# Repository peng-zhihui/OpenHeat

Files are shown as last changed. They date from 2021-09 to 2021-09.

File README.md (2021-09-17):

# OpenHeat：开源智能加热台

> 用于PCB回流焊的实用加热台，比较炫酷，可能目前市面上 **颜值最高** & **功能最强** 的加热台。

**参数：** 硬件方面基于`ESP32PICO-D4`芯片，输入电源`24V/10A`，最大功率200W，加热温度最高300℃；带蓝牙功能，***后续有空的话我会开发手机APP用于设置升温曲线*** 。

## 21-9-17 修复说明：

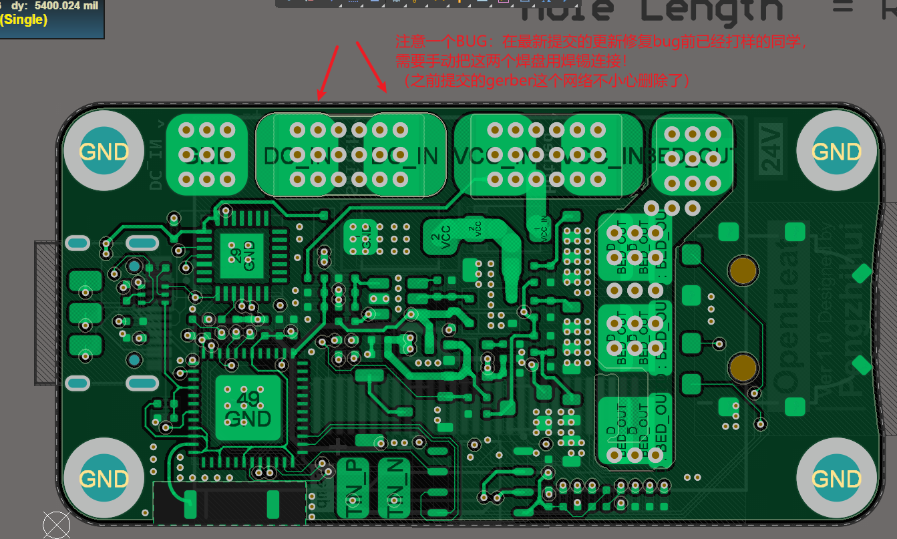
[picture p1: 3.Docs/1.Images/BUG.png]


---

## 关于本项目

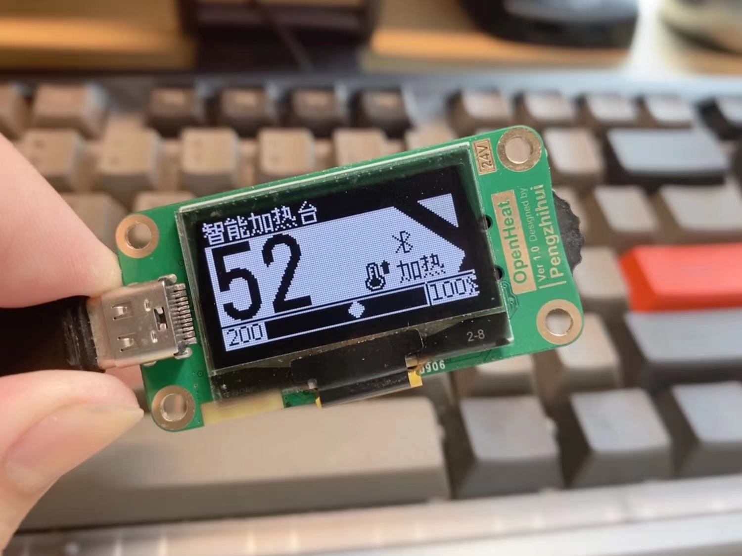
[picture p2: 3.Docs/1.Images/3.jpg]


* 本项目参考了 [createskyblue](https://gitee.com/createskyblue) / [OpenT12](https://gitee.com/createskyblue/OpenT12)开源T12电烙铁项目的固件，感谢这位同学设计的优秀交互动画体验，UI设计深得我心哈哈~

* 另外铝基板热床的设计采用了[MRobot-Origin](https://github.com/MRobot-Origin)/ [GS_Hbed](https://github.com/MRobot-Origin/GS_Hbed)同学的分型曲线设计，非常有创意~

## 使用说明

#### 1. 打样说明

直接用Hardware文件夹里的Gerber文件打样即可：主控制器为4层PCB，无特殊工艺要求；热床为铝基板PCB，可以在嘉立创打样。

> 铝基板是一种专门用来散热的PCB板材，大家看到的很多大功率LED灯珠就是这种，前阵子嘉立创开放了铝基板打样业务，还很便宜。所以相比于设计一个金属块做热床，这种方式不但成本低而且美观实用。

另外其实还有一块可选两层板作为固定件的，这个我还没来得及设计，也很简单，大家可以根据自己情况画一个，或者直接3D打印结构件固定也行。

#### 2. 固件说明

固件我这边是基于PlatformIO移植的，所以大家用这个平台的话直接打开下载就行了；如果是用Arduino IDE的话，先安装Library里面的库文件，然后一样下载。

固件库没有完全配置完成（因为原版固件是设计为电烙铁使用的），晚些我硬件都就位了会调试好固件供大家直接下载。

#### 3. 关于结构件

这个我也还在设计，我的风格肯定是以美观小巧为主，大家可以等我放出3D打印文件。

#### 4. 关于温度传感器

我这边是用的是K型热电偶，在PCB上已经集成了采集芯片，需要自己买一个表贴式的K型热电偶连接到板子下方的两个焊盘。

> 注意热电偶和热床的接触要绝缘，用高温胶带隔一下就行。另外热电偶是有极性的，如果发现加热后温度反而下降说明接反了。
>
> 现在代码中还没有加热电偶的代码，晚一点有空了会调好完整固件。大家自己添加也很容易，MAX6675使用SPI驱动，Arduino平台有很多例程。

#### 5. 关于元器件BOM

**注意！！！** C9电容一定要选耐压足够的，因为是并联到24V的VCC上，如果耐压不够短路的话可以看到烟花！！

#### 接线图

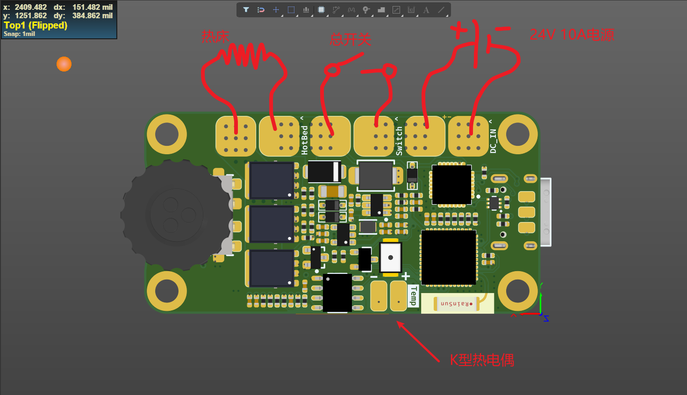
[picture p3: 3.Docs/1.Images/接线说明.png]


## 欢迎star支持 :D

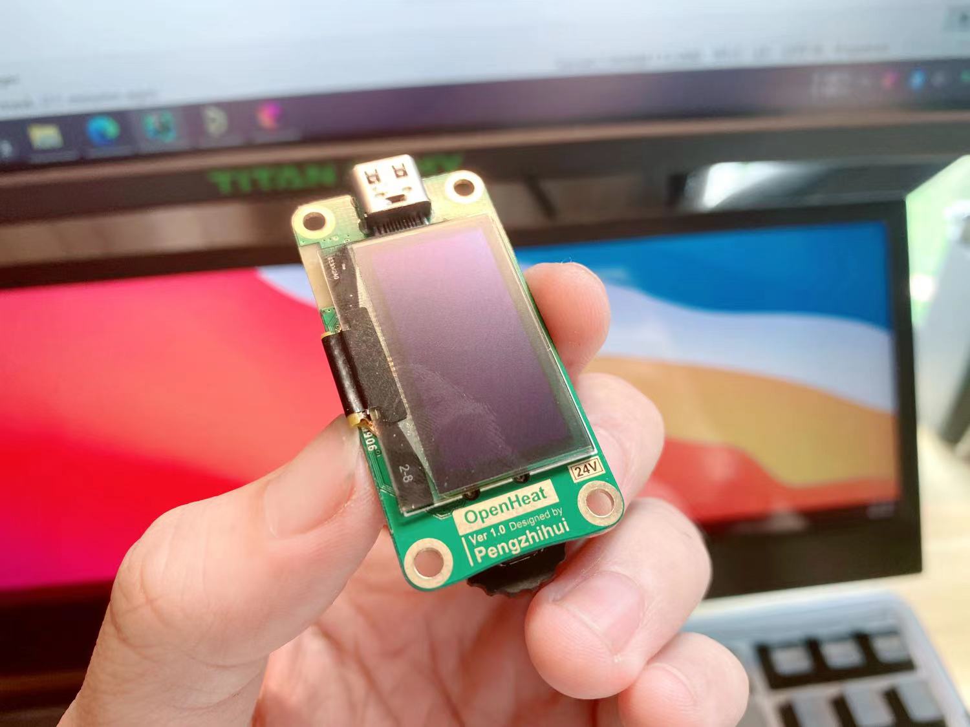
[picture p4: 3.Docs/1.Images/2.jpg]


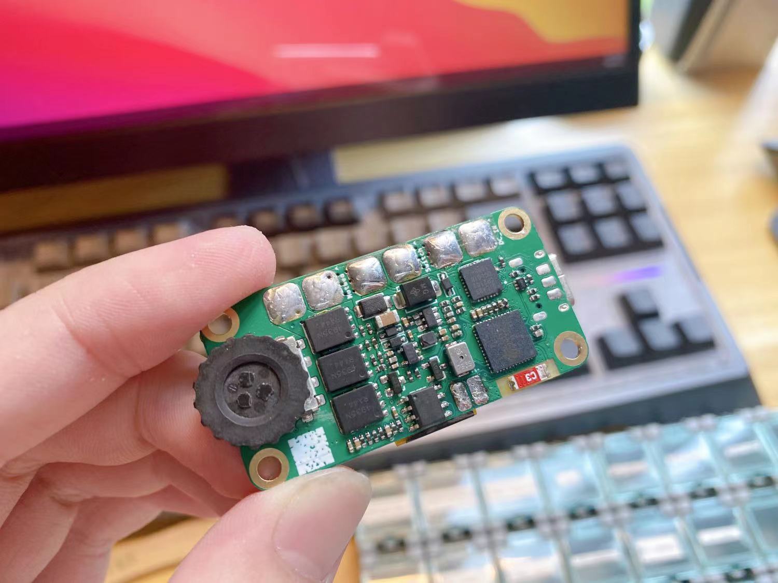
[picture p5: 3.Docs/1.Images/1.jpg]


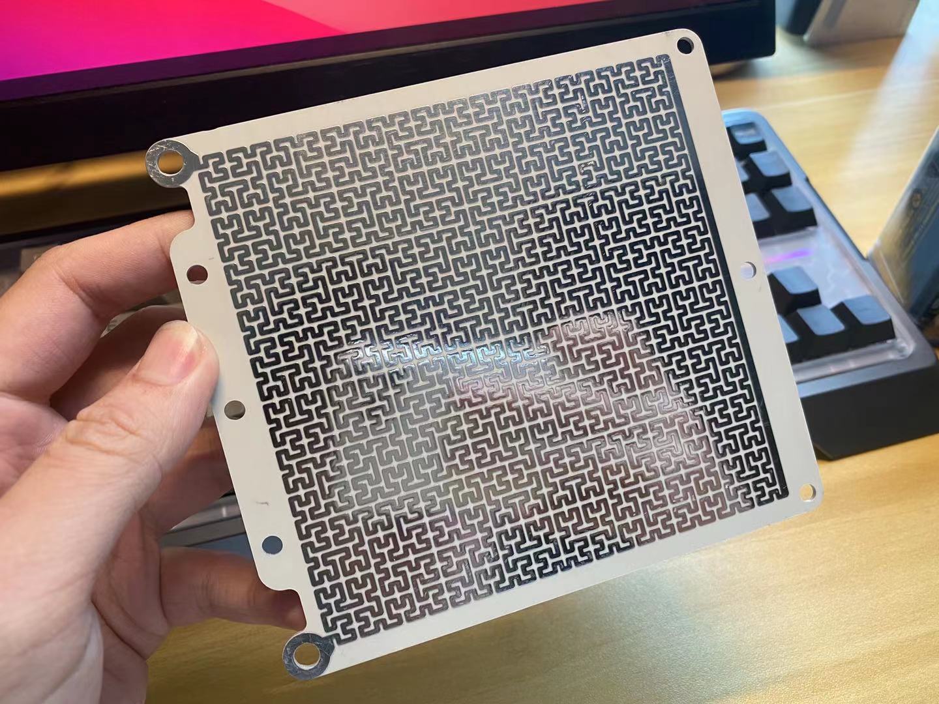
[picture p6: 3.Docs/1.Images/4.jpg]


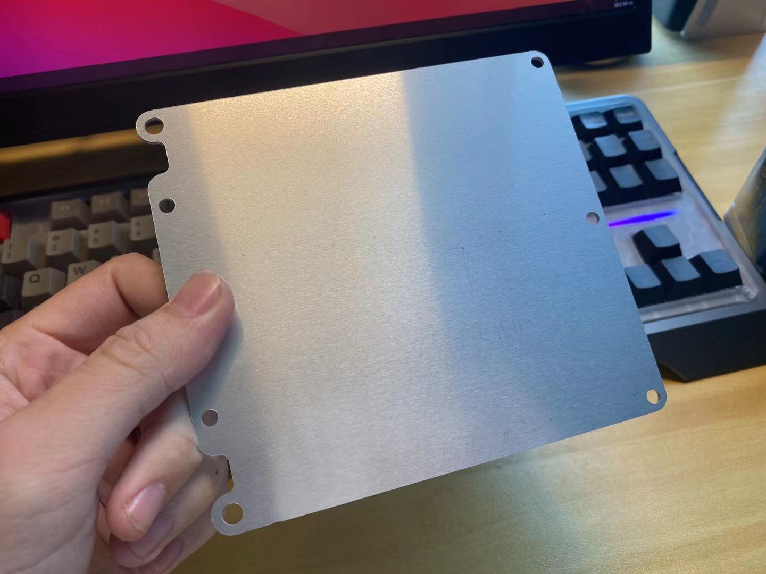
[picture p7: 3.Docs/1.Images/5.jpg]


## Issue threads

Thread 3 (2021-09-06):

用PCB走线发热做发热台可能会有最高温限制和使用寿命的问题

yzl893, 2021-09-06:
想法是非常的nice，不愧是稚晖大佬，不过用PCB走线加热感觉会有使用寿命的问题，高温会让铜箔和基板剥离导致失效，所以应该热床的温度不能太高，不过焊低温锡浆问题不大，就看耐用性怎么样了

peng-zhihui, 2021-09-07:
铝基板就是用来加热散热的，不是普通pcb，嘉立创现在可以做铝基板了很便宜

发自我的iPhone

------------------ 原始邮件 ------------------
发件人: yzl893 ***@***.***&gt;
发送时间: 2021年9月7日 00:26
收件人: peng-zhihui/OpenHeat ***@***.***&gt;
抄送: Subscribed ***@***.***&gt;
主题: 回复：[peng-zhihui/OpenHeat] 用PCB走线发热做发热台可能会有最高温限制和使用寿命的问题 (#3)

想法是非常的nice，不愧是稚晖大佬，不过用PCB走线加热感觉会有使用寿命的问题，高温会让铜箔和基板剥离导致失效，所以应该热床的温度不能太高，不过焊低温锡浆问题不大，就看耐用性怎么样了

—
You are receiving this because you are subscribed to this thread.
Reply to this email directly, view it on GitHub, or unsubscribe.
Triage notifications on the go with GitHub Mobile for iOS or Android.

Floyd-Fish, 2021-09-08:
> 铝基板就是用来加热散热的，不是普通pcb，嘉立创现在可以做铝基板了很便宜 发自我的iPhone
> […](#)
> ------------------ 原始邮件 ------------------ 发件人: yzl893 ***@***.***&gt; 发送时间: 2021年9月7日 00:26 收件人: peng-zhihui/OpenHeat ***@***.***&gt; 抄送: Subscribed ***@***.***&gt; 主题: 回复：[peng-zhihui/OpenHeat] 用PCB走线发热做发热台可能会有最高温限制和使用寿命的问题 (#3) 想法是非常的nice，不愧是稚晖大佬，不过用PCB走线加热感觉会有使用寿命的问题，高温会让铜箔和基板剥离导致失效，所以应该热床的温度不能太高，不过焊低温锡浆问题不大，就看耐用性怎么样了 — You are receiving this because you are subscribed to this thread. Reply to this email directly, view it on GitHub, or unsubscribe. Triage notifications on the go with GitHub Mobile for iOS or Android.

大佬有考虑过用恒温PTC陶瓷加热板作为发热器件吗

leazer, 2021-09-08:
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

之前我用PTC做过一个移动版的，直接陶瓷片容易被助焊剂粘脏，加了个铝板传热，奈何用的12v，功率不大够了，加热速度比较慢。

Floyd-Fish, 2021-09-08:
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

加热功率确实是个问题，如果用低压的陶瓷片可能功率不够，可以考虑用市电型号的+可控硅做，就是比较危险。。

yzl893, 2021-09-08:
> 铝基板就是用来加热散热的，不是普通pcb，嘉立创现在可以做铝基板了很便宜 发自我的iPhone
> […](#)
> ------------------ 原始邮件 ------------------ 发件人: yzl893 ***@***.***&gt; 发送时间: 2021年9月7日 00:26 收件人: peng-zhihui/OpenHeat ***@***.***&gt; 抄送: Subscribed ***@***.***&gt; 主题: 回复：[peng-zhihui/OpenHeat] 用PCB走线发热做发热台可能会有最高温限制和使用寿命的问题 (#3) 想法是非常的nice，不愧是稚晖大佬，不过用PCB走线加热感觉会有使用寿命的问题，高温会让铜箔和基板剥离导致失效，所以应该热床的温度不能太高，不过焊低温锡浆问题不大，就看耐用性怎么样了 — You are receiving this because you are subscribed to this thread. Reply to this email directly, view it on GitHub, or unsubscribe. Triage notifications on the go with GitHub Mobile for iOS or Android.

坐等成品测试了，电源也是一个需要考虑的问题，这么大大面积要达到300℃以上的话估计需要200W以上的功率，24V电源需要接近10A电流了，电源巨大且不便宜，看到有提用PD诱骗供电的，显示是不可能了，功率达不到。

ClimbSnail, 2021-09-12:
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

这个可以 https://github.com/ClimbSnail/HeatPlatform_SMT

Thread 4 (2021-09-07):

software

litter-hui, 2021-09-07:
我发现大佬之前说会把创作平台转移到ESP32上。现在真的真把这坑填上了。我本人也是电子爱好者，您能介绍一下您的软件平台吗，我在您之前那个esp32_pico的项目中编程过程中遇到一些问题，我用的是VScode+platformIO插件，希望以后您能多介绍一点软件方面的知识

peng-zhihui, 2021-09-18:
网上很多教程了，学一下platformIO一劳永逸

Closed 2021-09-24.

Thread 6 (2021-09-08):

供电问题

leazer, 2021-09-08:
看了下原理图，是采用外面的24v电源供电，没考虑动力电池的方案或者Type-c诱骗供电输出吗？
这样整体可以做到比较小巧，符合你一贯风格

yzl893, 2021-09-08:
不行的，PD最大只能提供20V5A的功率，也就是100W，要在这么大面积上维持300℃以上的高温，至少需要200W

yzl893, 2021-09-08:
> 看了下原理图，是采用外面的24v电源供电，没考虑动力电池的方案或者Type-c诱骗供电输出吗？
> 这样整体可以做到比较小巧，符合你一贯风格

不行的，PD最大只能提供20V5A的功率，也就是100W，要在这么大面积上维持300℃以上的高温，至少需要200W

leazer, 2021-09-09:
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

文件中的铝基加热板确实大了点。。。可以面积稍稍小些。做些小板子也够用了

tianyiqwq, 2021-09-14:
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
加热板的作者那有pd  #100w用的加热板，我也是打算直接用pd诱骗的。。。果然有人跟我想的一样

peng-zhihui, 2021-09-18:
淘宝24V 10A的电源很便宜的（50以内就有），我是固定焊台使用所以对电源体积没要求，而且想移动使用的话可以用6S的航模电池也很方便。

L1cardo, 2021-12-04:
我觉得可以做个电源内置方案，就放在工作是使用，可以获得较高的功率

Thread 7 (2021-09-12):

大佬热床超免费打样10x15尺寸了 能调整一下吗？

mlpzaq9998, 2021-09-12:

sosingle, 2021-09-14:
[我改了大小,孔位没有改动,(为了白嫖3D设计)捷配可以下单留下邮箱可以私发你

mlpzaq9998, 2021-09-14:
mlpzaq666888@gmail.com

sosingle, 2021-09-14:
> [mlpzaq666888@gmail.com](mailto:mlpzaq666888@gmail.com)

已发

xhzhu0628, 2021-09-14:
> > [mlpzaq666888@gmail.com](mailto:mlpzaq666888@gmail.com)
>
> 已发

同求，835525827@qq.com，感谢大佬！

Pwalk00, 2021-09-15:
> > [mlpzaq666888@gmail.com](mailto:mlpzaq666888@gmail.com)
>
> 已发

我也想要，1170714532@qq.com,感谢。

FranHawk, 2021-09-15:
> [我改了大小,孔位没有改动,(为了白嫖3D设计)捷配可以下单留下邮箱可以私发你

大佬我也想要，谢谢！645902989@qq.com

a850874651, 2021-09-16:
> [我改了大小,孔位没有改动,(为了白嫖3D设计)捷配可以下单留下邮箱可以私发你

大佬我也想要！！谢谢！  850874651@qq.com

13298331462, 2021-09-16:
> [我改了大小,孔位没有改动,(为了白嫖3D设计)捷配可以下单留下邮箱可以私发你

大佬，实在是想要啊！谢谢🙏597160233@qq.com

lanyker, 2021-09-19:
315921277@qq.com

lanyker, 2021-09-19:
感谢 lanyker@qq.com

Askly, 2021-09-19:
希望能分享一下，591760979@qq.com

guojinxin123, 2021-09-20:
da

> [我改了大小,孔位没有改动,(为了白嫖3D设计)捷配可以下单留下邮箱可以私发你

大佬大佬，我也好想要,1310643160@qq.com

Kol9974, 2021-09-21:
俺也想要！谢谢！1046889332@qq.com

MCWD, 2021-09-21:
> > [mlpzaq666888@gmail.com](mailto:mlpzaq666888@gmail.com)
>
> 已发

同求，WD90070@126.com，谢谢

sosingle, 2021-09-21:
发不过来,大家可以去这里下载https://github.com/sosingle/Heatbed_fixed

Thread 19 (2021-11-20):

热床阻值升高限制加热功率

aicsyou, 2021-11-20:
用30V的电源测试热床加热温度，发现随着温度升高，热床温度升高到200度左右，阻值从3欧姆升高到5欧姆左右，最终加热功率160W
因为固定热偶的材料不够耐热，所以没有继续升温，还不确定最终温度

24V/10A电源的功率只能提供快速升温，但是最高温度无法保证

测试条件》台式电源30V/10A， 陶瓷底座隔热
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

song-hailong, 2021-11-30:
我用的24v 10A的电源，能加热到260℃，然后就加不上去了

aicsyou, 2021-12-01:
> 我用的24v 10A的电源，能加热到260℃，然后就加不上去了

我用24V只能到165°C，请问你是用了什么效果好的隔热材料么？或者热床的阻值更低？

yjc-2004, 2021-12-04:
老哥，你这个控制板是分布的吗，开源吗

aicsyou, 2021-12-04:
> 老哥，你这个控制板是分布的吗，开源吗

我就是把稚辉君的设计调整了一下，方便手残党焊接，还在测试，可以看我fork后的easyBuild branch

song-hailong, 2021-12-05:
> > 我用的24v 10A的电源，能加热到260℃，然后就加不上去了
>
> 我用 24V 只能到 165°C，请问你是用什么健康的隔热材料吗？或者热床的阻值吗？

没有，我是直接加热的，可能是程序的原因，程序里面有个读取ADC值，在读取ADC的时候会把加热关了，我把这部分代码删了。

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

询问：我之前直接回复的邮件，怎么不会同步到这里来？我用的QQ邮箱，是需要怎么操作吗？

aicsyou, 2021-12-05:
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

我拿掉底座重新试了一下，这次温度能到200摄氏度了，看来底座热阻比空气低一些，还是悬空比较好。和你的加热台相比估计我的线缆的电阻也稍微限制了一点加热功率。不过总的来说应该很难到300摄氏度了，除非升高电压或者缩小加热台

另加热的时候有味道，估计是preprag本身不适合这个温度，颜色有明显变化

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

song-hailong, 2021-12-06:
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

是的，但是200摄氏度就可以融化锡浆了，温度够用就行。

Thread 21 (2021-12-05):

是否含有烙铁部分

L1cardo, 2021-12-05:
看到代码里面有“烙铁头”字样，但是此项目名称又叫“开源智能加热台”，所以请问，这个项目完成后会包含烙铁部分吗？如果是的话就太好了。
如果不包含烙铁，那我就先自己diy一个了，现在比较纠结😅。

song-hailong, 2021-12-05:
这个代码，原版就是一个T12烙铁项目[skyblue OpenT12](https://gitee.com/createskyblue/OpenT12)

L1cardo, 2021-12-05:
> 这个代码，原版就是一个T12烙铁项目[skyblue OpenT12](https://gitee.com/createskyblue/OpenT12)

这个我是了解的，我就想知道稚晖君这个项目完成后是否会包含烙铁，还是说只是加热台。

Closed 2023-03-17.

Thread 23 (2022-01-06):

处于强制停机界面时，波浪报警声工作不正常的解决方法

createskyblue, 2022-01-06:
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

在强制关机页面中，波浪警告声发生器没有使用音乐播放器接口，
而是实时计算音效进行播放

但是由于Display()中会自动调用音乐播放器事件(PlaySoundLoop)，
音乐播放函数因   没有需要播放的音乐  从而会强制关闭音频接口输出
导致无法正常播放波浪警告声

解决方案请参考OpenT12新版 程序
https://github.com/createskyblue/OpenT12
Event.cpp : 206
Beep.cpp 中的PlaySoundLoop()

具体措施：设置flag 进入报警界面时关闭音乐播放器检查事件

createskyblue, 2022-01-06:
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

Closed 2022-11-03.

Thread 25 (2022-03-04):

【求助】关于6.8uH IND-201612电感

Chen-Yixing123, 2022-03-04:
这个封装的电感立创商城买不到，是在哪里有啊？
还有如图红圈焊电感的位置为什么没有焊盘，是要自己刮出来吗？还是怎么处理？
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

Cardistalive, 2022-03-07:
> 为什么没有焊盘，是要自己刮出来

有没有BOM表可以直接导入呀，我在立创商城挑了一上午，还是没下好单，不知道怎么用其他有货的商品替换没货的

dgsx61, 2022-03-08:
找2016封装的电感 201612指的是20*16 12高

Cardistalive, 2022-03-20:
> 这个封装的电感立创商城买不到，是在哪里有啊？ 还有如图红圈焊电感的位置为什么没有焊盘，是要自己刮出来吗？还是怎么处理？ 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

请问您已经焊接完了吗？我按关键词“201612 6.8uH”搜索到的是0806封装的电感

Cardistalive, 2022-03-20:
> 找2016封装的电感 201612指的是20*16 12高

请问您焊接好了吗？我找20*16 6.8uH的电感找不到

dgsx61, 2022-03-20:
>
我在立创找了个22UH的

Cardistalive, 2022-03-20:
> >
>
> 我在立创找了个22UH的

焊接好后可以正常使用吗

dgsx61, 2022-03-20:
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

可

Cardistalive, 2022-03-20:
> >
>
> 我在立创找了个22UH的

焊接好后可以正常使用吗

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

好的，谢谢

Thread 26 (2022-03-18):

请问下必须插TYPEC才能开机吗？

dgsx61, 2022-03-18:
我这边连接12V/24V供电后，必须插一下TYPEC才能启动

dgsx61, 2022-03-18:
启动后拔掉typec保持开机。

dgsx61, 2022-03-18:
启动后拔掉typec，会保持一段时间开机状态，然后假死，不能操作，再插上typec又继续工作，注意是继续不是重新开机。

Cardistalive, 2022-03-20:
> 我这边连接12V/24V供电后，必须插一下TYPEC才能启动

24V电源哪里购买哒，有没有链接给个

dgsx61, 2022-03-20:
> > 我这边连接12V/24V供电后，必须插一下TYPEC才能启动
>
> 24V电源哪里购买哒，有没有链接给个

淘宝24V开关电源 直接买就行了 又不是什么高科技东西

dgsx61, 2022-03-20:
解决办法：更改VBUS和5V的防倒流二极管位置，确保串口芯片能启动。

Cardistalive, 2022-03-20:
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

好的，谢谢

Closed 2022-03-21.

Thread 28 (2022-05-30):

为何要选3个MOS管并联，感谢赐教！

RunZeJustin, 2022-05-30:
请问一下，为何要选用3个MOS管并联？对于这个项目预期10A200W，而选用的MOS管60V150A一个不够用吗？我知道并联是为了均流，但这是不是冗余了？还是说3个并联仅仅是为了更好散热？为何不是2个、4个？这里有什么讲究吗？感谢赐教！

TPAXcc, 2022-06-07:
应该是分摊发热，毕竟这板没散热片

TPAXcc, 2022-06-07:
至于为什么不是 4 个... 应该是放不下了

RunZeJustin, 2022-06-10:
@TPAXcc 多谢哈

RunZeJustin, 2022-06-10:
@TPAXcc 多谢哈

TPAXcc, 2022-06-10:
> @TPAXcc 多谢哈

客气，互相学习。我也刚入门

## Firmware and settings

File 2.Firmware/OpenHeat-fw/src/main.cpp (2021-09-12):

#include <Arduino.h>
#include "OpenT12.h"

BluetoothSerial SerialBT;
#if !defined(CONFIG_BT_ENABLED) || !defined(CONFIG_BLUEDROID_ENABLED)
#error Bluetooth is not enabled! Please run `make menuconfig` to and enable it
#endif

OneButton RButton(BUTTON_PIN, true);
U8G2_SSD1306_128X64_NONAME_F_HW_I2C Disp(U8G2_R0, /* reset=*/ U8X8_PIN_NONE, /* clock=*/ 22, /* data=*/21);
PID MyPID(&TipTemperature, &PID_Output, &PID_Setpoint, aggKp, aggKi, aggKd, DIRECT);
/////////////////////////////////////////////////////////////////

char* TipName = "文件系统错误：请上报";

float BootTemp = 200;      //开机温度          (°C)
float SleepTemp = 80;     //休眠温度          (°C)
float BoostTemp = 50;      //爆发模式升温幅度   (°C)

float ShutdownTime = 0;      //关机提醒              (分)
float SleepTime = 10;      //休眠触发时间          (分)
float ScreenProtectorTime = 60;     //屏保在休眠后的触发时间(秒)
float BoostTime = 60;     //爆发模式持续时间      (秒)


bool SYS_Ready = false;
//烙铁头事件
bool TipInstallEvent = true;
bool TipCallSleepEvent = false;
//到温提示音播放完成
bool TempToneFlag = false;
//休眠后屏保延迟显示标志
bool SleepScreenProtectFlag = false;
//温控系统状态
bool ERROREvent = false;
bool ShutdownEvent = false;
bool SleepEvent = false;
bool BoostEvent = false;
bool UnderVoltageEvent = false;
//PWM控制状态
bool PWM_WORKY = false;

uint8_t PIDMode = true;
uint8_t Use_KFP = true;
uint8_t PanelSettings = PANELSET_Detailed;
uint8_t ScreenFlip = false;
uint8_t SmoothAnimation_Flag = true;
float ScreenBrightness = 128;
uint8_t OptionStripFixedLength_Flag = false;

uint8_t Volume = true;
uint8_t RotaryDirection = false;
uint8_t HandleTrigger = HANDLETRIGGER_VibrationSwitch;

double SYS_Voltage = 3.3;
float UndervoltageAlert = 3;
char BootPasswd[20] = {0};
uint8_t Language = LANG_Chinese;
uint8_t MenuListMode = false;

float ADC_PID_Cycle = 100;

//面板状态条
uint8_t TempCTRL_Status = TEMP_STATUS_OFF;
uint8_t* C_table[] = {c1, c2, c3, Lightning, c5, c6, c7};
char* TempCTRL_Status_Mes[] = {
    "错误",
    "停机",
    "休眠",
    "提温",
    "正常",
    "加热",
    "维持",
};

//系统信息
uint64_t ChipMAC;
char ChipMAC_S[19] = {0};
char CompileTime[20];

/////////////////////////////////////////////////////////////////

//先初始化硬件->显示LOGO->初始化软件
void setup()
{
    //关闭中断
    noInterrupts();

    ////////////////////////////初始化硬件/////////////////////////////
    //获取系统信息
    ChipMAC = ESP.getEfuseMac();
    sprintf(CompileTime, "%s %s", __DATE__, __TIME__);
    for (uint8_t i = 0; i < 6; i++)
        sprintf(ChipMAC_S + i * 3, "%02X%s", ((uint8_t*) &ChipMAC)[i], (i != 5) ? ":" : "");

    //初始化串口
    Serial.begin(115200);

    //初始化GPIO
    BeepInit();                     //蜂鸣器

    pinMode(POWER_ADC_PIN, INPUT);  //主电压分压检测ADC


    //初始化烙铁头
    TipControlInit();

    //初始化编码器
    sys_RotaryInit();

    //初始化OLED
    Disp.begin();
    Disp.setBusClock(921600);
    Disp.enableUTF8Print();
    Disp.setFontDirection(0);
    Disp.setFontPosTop();
    Disp.setFont(u8g2_font_wqy12_t_gb2312);
    Disp.setDrawColor(1);
    Disp.setFontMode(1);

    ////////////////////////////初始化软件/////////////////////////////
    //显示启动信息
    //ShowBootMsg();

    //启动文件系统，并读取存档
    FilesSystemInit();

    //初始化命令解析器
    shellInit();

    //初始化蓝牙（可选）
    BLE_Init();

    SetSound(BootSound); //播放音效

    //初始化UI
    System_UI_Init();

    //首次启动的时候根据启动温度配置，重新设定目标温度
    sys_Counter_SetVal(BootTemp);

    //载入烙铁头配置
    LoadTipConfig();

    //显示Logo
//    EnterLogo();

    //开机密码
    while (!EnterPasswd())
    {
        Pop_Windows("身份验证失败");
    }
    SYS_Ready = true;

}

void loop()
{
    //获取按键
    sys_KeyProcess();

    if (!Menu_System_State)
    {
        //温度闭环控制
        TemperatureControlLoop();
        //更新系统事件：：系统事件可能会改变功率输出
        TimerEventLoop();
    }


    //更新状态码
    SYS_StateCode_Update();
    //设置输出功率
    SetPOWER(PID_Output);

    //刷新UI
    System_UI();
}
/**
 * @description: 计算主电源电压
 * @param {*}
 * @return 主电源电压估计值
 */
double Get_MainPowerVoltage(void)
{
    //uint16_t POWER_ADC = analogRead(POWER_ADC_PIN);
    double TipADC_V_R2 = analogReadMilliVolts(POWER_ADC_PIN) / 1000.0;
    //double   TipADC_V_R2 = ESP32_ADC2Vol(POWER_ADC);
    double TipADC_V_R1 = (TipADC_V_R2 * POWER_ADC_VCC_R1) / POWER_ADC_R2_GND;

    SYS_Voltage = TipADC_V_R1 + TipADC_V_R2;
    return SYS_Voltage;
}

void SYS_Reboot(void)
{
    ESP.restart();
}

void About(void)
{
    //播放Logo动画
    EnterLogo();
    //生成项目QRCode
    QRCode qrcode;
    uint8_t qrcodeData[qrcode_getBufferSize(3)];

    switch (Language)
    {
        case LANG_Chinese:
            qrcode_initText(&qrcode, qrcodeData, 3, 0, "https://gitee.com/createskyblue/OpenT12");
            break;

        default:
            qrcode_initText(&qrcode, qrcodeData, 3, 0, "https://github.com/createskyblue/OpenT12");
            break;
    }

    Clear();

    uint8_t x_offset = (SCREEN_COLUMN - qrcode.size * 2) / 2;
    uint8_t y_offset = (SCREEN_ROW - qrcode.size * 2) / 2;

    for (uint8_t y = 0; y < qrcode.size; y++)
        for (uint8_t x = 0; x < qrcode.size; x++)
            if (qrcode_getModule(&qrcode, x, y))
                Draw_Pixel_Resize(x + x_offset, y + y_offset, x_offset, y_offset, 2, 2);

    Disp.setDrawColor(2);
    Disp.drawBox(x_offset - 2, y_offset - 2, qrcode.size * 2 + 4, qrcode.size * 2 + 4);
    Disp.setDrawColor(1);

    while (!sys_KeyProcess())
    {
        Display();
    }

}

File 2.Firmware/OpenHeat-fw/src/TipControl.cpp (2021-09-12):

#include "OpenT12.h"

//[既然有了nmos 为啥还要pmos]科普:https://www.bilibili.com/video/BV1Mb4y1k7fd?from=search&seid=15411923932488650975

enum MOS_Type
{
    PMOS = 0,
    NMOS
};
//PWM
uint8_t PWM_Freq = 2000;    // 频率
uint8_t PWM1_Channel = 0;    // 通道
uint8_t PWM2_Channel = 0;    // 通道
uint8_t PWM_Resolution = 8;   // 分辨率
//基础温控
uint8_t MyMOS = PMOS;
uint8_t POWER = 0;
uint8_t PWM = 0;
uint8_t LastPWM = 0;
uint16_t LastADC = 0;
double TipTemperature = 0;
double PID_Output = 0;
double PID_Setpoint = 0;
double TempGap = 0;
uint32_t ADCSamplingInterval = 0; //ADC采样间隔(ms)
//PID
float aggKp = 30.0, aggKi = 0, aggKd = 0.5;
float consKp = 20.0, consKi = 1, consKd = 0.5;

//初始化烙铁头温控系统
void TipControlInit(void)
{
    //初始化ADC输入GPIO
    pinMode(TIP_ADC_PIN, INPUT_PULLUP); //ADC

    ledcAttachPin(PWM1_PIN, PWM1_Channel);  // 绑定PWM1通道
    ledcSetup(PWM1_Channel, PWM_Freq, PWM_Resolution); // 设置PWM1通道

    if (PWM2_PIN != -1)
    {
        ledcAttachPin(PWM2_PIN, PWM2_Channel);  // 绑定PWM2通道
        ledcSetup(PWM2_Channel, PWM_Freq, PWM_Resolution); // 设置PWM2通道
    }

    SetPOWER(0); //关闭功率管输出

    if (SW_PIN != -1)
    {
        //初始化SW-PIN休眠检测引脚
        pinMode(SW_PIN, INPUT_PULLUP);
        //初始化SW-PIN休眠检测引脚中断 (尽可能减少中断的使用)
        //attachInterrupt(SW_PIN, SW_IRQHandler, CHANGE);
    }

    //初始化烙铁头PID
    MyPID.SetOutputLimits(0, 255); //PID输出限幅
    MyPID.SetMode(AUTOMATIC); //PID控制模式
    MyPID.SetSampleTime(10); //PID采样时间
}

//计算实际温度
double CalculateTemp(double ADC, double P[])
{
    TipTemperature = P[0] + ADC * P[1] + ADC * ADC * P[2] + ADC * ADC * ADC * P[3];
    return TipTemperature;
}

//PWM输出模块
uint8_t PWMOutput_Lock = true;
void PWMOutput(uint8_t pwm)
{
    PWM_WORKY = true;
    //PWM锁
    if (PWMOutput_Lock || ShutdownEvent || Menu_System_State || ERROREvent)
    {
        PWM_WORKY = false;
        // Log(LOG_INFO,"输出被限制");
        // printf("输出被限制 PWMOutput_Lock=%d ShutdownEvent=%d Menu_System_State=%d ERROREvent=%d\n", PWMOutput_Lock, ShutdownEvent, Menu_System_State, ERROREvent);
        if (MyMOS == PMOS) pwm = 255;
        else pwm = 0;

        // //软件指示灯
        // digitalWrite(LED_Pin ,LOW);
    }
    //printf("PWM:%d\n",pwm);
    if (LastPWM != pwm)
    {
        if (pwm == 255) ledcWrite(PWM1_Channel, 256);
        else ledcWrite(PWM1_Channel, pwm);

        LastPWM = pwm;
    }

}

/**
 *调用卡尔曼滤波器 实践
 */
KFP KFP_Temp = {0.02, 0, 0, 0, 0.01, 4.5};
float SamplingRatioWork = 10;           //采样/加热 比率
//获取ADC读数
int GetADC0(void)
{
    static uint32_t ADCSamplingTime = 0; //上次采样时间
    static uint32_t ADCReadCoolTimer = 0;

    if (SYS_Ready)
    {

        ADCSamplingInterval = millis() - ADCSamplingTime;
        if (ADCSamplingInterval < ADC_PID_Cycle * (9 / 10.0)) return LastADC; //9/10周期ADC不应该工作，应该把时间留给加热

        //若原输出非关闭，则在关闭输出后等待一段时间，因为电热偶和加热丝是串在一起的，只有不加热的时候才能安全访问热偶温度
        if (PWMOutput_Lock == false)
        {
            ADCReadCoolTimer = millis();
            //锁定功率管输出：必须要关闭MOS管才能成功读取电热偶
            PWMOutput_Lock = true;
        }

        if (millis() - ADCReadCoolTimer <= ADC_PID_Cycle / 10)
        {
            return -1; //数据未准备好
        }

    }

    //读取并平滑滤波经过运算放大器放大后的热偶ADC数据
    uint16_t ADC_RAW = analogRead(TIP_ADC_PIN);
    uint16_t ADC;

    //卡尔曼滤波器
    if (Use_KFP) ADC = kalmanFilter(&KFP_Temp, (float) ADC_RAW);
    else ADC = ADC_RAW;
    //printf("%d,%d\r\n", ADC_RAW,ADC);

    //解锁功率管输出：前提是没有打开菜单
    if (!Menu_System_State)
        PWMOutput_Lock = false;

    //记录采样间隔时间
    ADCSamplingTime = millis();

    LastADC = ADC;
    return LastADC;
}

//设置输出功率
void SetPOWER(uint8_t power)
{

    POWER = power;
    //MOS管分类处理
    if (MyMOS == PMOS)
    {
        //PMOS 低电平触发
        PWM = 255 - power;
    }

    PWMOutput(PWM);
}

float ADC_PID_Cycle_List[3] = {200, 100, 50};
//温度控制循环
void TemperatureControlLoop(void)
{
    Clear();
    char buffer[50];
    int ADC;

    PID_Setpoint = sys_Counter_Get();
    if (BoostEvent)
    {
        //短时功率加成
        PID_Setpoint += BoostTemp;
    } else if (SleepEvent)
    {
        PID_Setpoint = SleepTemp;
    }

    PID_Setpoint = constrain(PID_Setpoint, TipMinTemp, TipMaxTemp);
    //尝试访问ADC
    ADC = GetADC0();
    if (ADC != -1)
    {

        TipTemperature = CalculateTemp((double) LastADC, PTemp);
        TempGap = abs(PID_Setpoint - TipTemperature);

        //根据温差选择合适的ADC-PID采样周期
        if (TempGap > 150) ADC_PID_Cycle = ADC_PID_Cycle_List[0];
        else if (TempGap > 50) ADC_PID_Cycle = ADC_PID_Cycle_List[1];
        else ADC_PID_Cycle = ADC_PID_Cycle_List[2];

        /////////////////////////////////////////////////////////////////////////////////////////////
        //控温模式
        if (PIDMode)
        {
            //PID模式

            //根据温度差选择最优的PID配置，PID参数可被Shell实时更改
            if (TempGap < 30) MyPID.SetTunings(consKp, consKi, consKd);
            else MyPID.SetTunings(aggKp, aggKi, aggKd);
            //更新PID采样时间：采样时间可被Shell实时更改
            //MyPID.SetSampleTime(PIDSampleTime);
            MyPID.SetSampleTime(ADC_PID_Cycle);

            //尝试计算PID
            //printf("计算PID：%d\n PID输出:%lf", MyPID.Compute(), PID_Output);
            MyPID.Compute();

        } else
        {
            //模糊模式
            if (TipTemperature < PID_Setpoint) PID_Output = 255;
            else PID_Output = 0;
        }


        //串口打印温度
        //printf("Temp:%lf,%lf,%d\r\n", TipTemperature, PID_Setpoint, ADC);

        /////////////////////////////////////////////////////////////////////////////////////////////
    }
}

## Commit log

2021-09-05 [Hw] Add PCB files.
    [HotBed-24V.GBL, HotBed-24V.GBO, HotBed-24V.GBP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]
2021-09-14 Update something.
    [Main.SchDoc, OpenHeat.PrjPCB]
2021-09-17 [Hw] Fixed PCB Net missing bug.
    添加了接线图说明。
    [Main.SchDoc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]
2021-09-17 Update README.
    [OpenHeat.PrjPCB]
